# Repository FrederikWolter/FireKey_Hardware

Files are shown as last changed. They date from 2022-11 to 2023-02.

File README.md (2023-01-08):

<p align="center">
  
</p>

# FireKey - Hardware

This student research project named *FireKey* is part of the winter semester 2022 and summer semester 2023 in the
Applied Computer Science course at DHBW Mannheim. The aim is to create a macro keyboard with individually configurable
keys that allow the input of simple key combinations up to more complex sequences.

This repository is used for developing the *hardware* of *FireKey*. The corresponding firmware is developed in
the [FireKey_Firmware](https://github.com/FrederikWolter/FireKey_Firmware) repository and the configuration software
in [FireKey_Configurator](https://github.com/FrederikWolter/FireKey_Configurator).

## Structure

### *PCB*

Work in progress TODO

### *PCB_theory*

Work in progress TODO

### *3D_printing*

Work in progress TODO

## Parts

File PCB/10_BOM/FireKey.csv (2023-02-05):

Source: | C:\Users\dvd62\OneDrive\05_Semester_5_WiSe\90_Studienarbeit\FireKey_Hardware\PCB\FireKey.kicad_sch
Date: | 2/5/2023 1:17:39 PM
Tool: | Eeschema (6.0.10)
Generator: | C:\Program Files\KiCad\6.0\bin\scripting\plugins/bom_csv_grouped_by_value.py
Component Count: | 65
Individual Components:
Item | Qty | Reference(s) | Value | LibPart | Footprint | Datasheet | Part# | Supplier
 |  | C0 | 100nF | Device:C | Capacitor_SMD:C_0603_1608Metric_Pad1.08x0.95mm_HandSolder | https://www.lcsc.com/product-detail/C694249.html | C694249 | LCSC
 |  | C1 | 100nF | Device:C | Capacitor_SMD:C_0603_1608Metric_Pad1.08x0.95mm_HandSolder | https://www.lcsc.com/product-detail/C694249.html | C694249 | LCSC
 |  | C2 | 100nF | Device:C | Capacitor_SMD:C_0603_1608Metric_Pad1.08x0.95mm_HandSolder | https://www.lcsc.com/product-detail/C694249.html | C694249 | LCSC
 |  | C3 | 100nF | Device:C | Capacitor_SMD:C_0603_1608Metric_Pad1.08x0.95mm_HandSolder | https://www.lcsc.com/product-detail/C694249.html | C694249 | LCSC
 |  | C4 | 100nF | Device:C | Capacitor_SMD:C_0603_1608Metric_Pad1.08x0.95mm_HandSolder | https://www.lcsc.com/product-detail/C694249.html | C694249 | LCSC
 |  | C5 | 100nF | Device:C | Capacitor_SMD:C_0603_1608Metric_Pad1.08x0.95mm_HandSolder | https://www.lcsc.com/product-detail/C694249.html | C694249 | LCSC
 |  | C6 | 100nF | Device:C | Capacitor_SMD:C_0603_1608Metric_Pad1.08x0.95mm_HandSolder | https://www.lcsc.com/product-detail/C694249.html | C694249 | LCSC
 |  | C7 | 100nF | Device:C | Capacitor_SMD:C_0603_1608Metric_Pad1.08x0.95mm_HandSolder | https://www.lcsc.com/product-detail/C694249.html | C694249 | LCSC
 |  | C8 | 100nF | Device:C | Capacitor_SMD:C_0603_1608Metric_Pad1.08x0.95mm_HandSolder | https://www.lcsc.com/product-detail/C694249.html | C694249 | LCSC
 |  | C9 | 100nF | Device:C | Capacitor_SMD:C_0603_1608Metric_Pad1.08x0.95mm_HandSolder | https://www.lcsc.com/product-detail/C694249.html | C694249 | LCSC
 |  | C10 | 100nF | Device:C | Capacitor_SMD:C_0603_1608Metric_Pad1.08x0.95mm_HandSolder | https://www.lcsc.com/product-detail/C694249.html | C694249 | LCSC
 |  | C11 | 100nF | Device:C | Capacitor_SMD:C_0603_1608Metric_Pad1.08x0.95mm_HandSolder | https://www.lcsc.com/product-detail/C694249.html | C694249 | LCSC
 |  | C12 | 100nF | Device:C | Capacitor_SMD:C_0603_1608Metric_Pad1.08x0.95mm_HandSolder | https://www.lcsc.com/product-detail/C694249.html | C694249 | LCSC
 |  | C13 | 100nF | Device:C | Capacitor_SMD:C_0603_1608Metric_Pad1.08x0.95mm_HandSolder | https://www.lcsc.com/product-detail/C694249.html | C694249 | LCSC
 |  | C14 | 100nF | Device:C | Capacitor_SMD:C_0603_1608Metric_Pad1.08x0.95mm_HandSolder | https://www.lcsc.com/product-detail/C694249.html | C694249 | LCSC
 |  | D1 | 1N4148W | Device:D | Custom_Parts:D_SOD-123 | https://www.lcsc.com/product-detail/C2892570.html | C2892570 | LCSC
 |  | D2 | 1N4148W | Device:D | Custom_Parts:D_SOD-123 | https://www.lcsc.com/product-detail/C2892570.html | C2892570 | LCSC
 |  | D3 | 1N4148W | Device:D | Custom_Parts:D_SOD-123 | https://www.lcsc.com/product-detail/C2892570.html | C2892570 | LCSC
 |  | D4 | 1N4148W | Device:D | Custom_Parts:D_SOD-123 | https://www.lcsc.com/product-detail/C2892570.html | C2892570 | LCSC
 |  | D5 | 1N4148W | Device:D | Custom_Parts:D_SOD-123 | https://www.lcsc.com/product-detail/C2892570.html | C2892570 | LCSC
 |  | D6 | 1N4148W | Device:D | Custom_Parts:D_SOD-123 | https://www.lcsc.com/product-detail/C2892570.html | C2892570 | LCSC
 |  | D7 | 1N4148W | Device:D | Custom_Parts:D_SOD-123 | https://www.lcsc.com/product-detail/C2892570.html | C2892570 | LCSC
 |  | D8 | 1N4148W | Device:D | Custom_Parts:D_SOD-123 | https://www.lcsc.com/product-detail/C2892570.html | C2892570 | LCSC
 |  | D9 | 1N4148W | Device:D | Custom_Parts:D_SOD-123 | https://www.lcsc.com/product-detail/C2892570.html | C2892570 | LCSC
 |  | D10 | 1N4148W | Device:D | Custom_Parts:D_SOD-123 | https://www.lcsc.com/product-detail/C2892570.html | C2892570 | LCSC
 |  | D11 | 1N4148W | Device:D | Custom_Parts:D_SOD-123 | https://www.lcsc.com/product-detail/C2892570.html | C2892570 | LCSC
 |  | D12 | 1N4148W | Device:D | Custom_Parts:D_SOD-123 | https://www.lcsc.com/product-detail/C2892570.html | C2892570 | LCSC
 |  | D13 | 1N4148W | Device:D | Custom_Parts:D_SOD-123 | https://www.lcsc.com/product-detail/C2892570.html | C2892570 | LCSC
 |  | D14 | 1N4148W | Device:D | Custom_Parts:D_SOD-123 | https://www.lcsc.com/product-detail/C2892570.html | C2892570 | LCSC
 |  | D15 | 1N4148W | Device:D | Custom_Parts:D_SOD-123 | https://www.lcsc.com/product-detail/C2892570.html | C2892570 | LCSC
 |  | KEY1 | SW_MX | Custom_Parts:SW_MX_1u | Custom_Parts:SW_Cherry_MX_1.00u_PCB_CleanFront | https://de.aliexpress.com/item/1005003981373212.html | - | AliExpress
 |  | KEY2 | SW_MX | Custom_Parts:SW_MX_1u | Custom_Parts:SW_Cherry_MX_1.00u_PCB_CleanFront | https://de.aliexpress.com/item/1005003981373212.html | - | AliExpress
 |  | KEY3 | SW_MX | Custom_Parts:SW_MX_1u | Custom_Parts:SW_Cherry_MX_1.00u_PCB_CleanFront | https://de.aliexpress.com/item/1005003981373212.html | - | AliExpress
 |  | KEY4 | SW_MX | Custom_Parts:SW_MX_1u | Custom_Parts:SW_Cherry_MX_1.00u_PCB_CleanFront | https://de.aliexpress.com/item/1005003981373212.html | - | AliExpress
 |  | KEY5 | SW_MX | Custom_Parts:SW_MX_1u | Custom_Parts:SW_Cherry_MX_1.00u_PCB_CleanFront | https://de.aliexpress.com/item/1005003981373212.html | - | AliExpress
 |  | KEY6 | SW_MX | Custom_Parts:SW_MX_1u | Custom_Parts:SW_Cherry_MX_1.00u_PCB_CleanFront | https://de.aliexpress.com/item/1005003981373212.html | - | AliExpress
 |  | KEY7 | SW_MX | Custom_Parts:SW_MX_1u | Custom_Parts:SW_Cherry_MX_1.00u_PCB_CleanFront | https://de.aliexpress.com/item/1005003981373212.html | - | AliExpress
 |  | KEY8 | SW_MX | Custom_Parts:SW_MX_1u | Custom_Parts:SW_Cherry_MX_1.00u_PCB_CleanFront | https://de.aliexpress.com/item/1005003981373212.html | - | AliExpress
 |  | KEY9 | SW_MX | Custom_Parts:SW_MX_1u | Custom_Parts:SW_Cherry_MX_1.00u_PCB_CleanFront | https://de.aliexpress.com/item/1005003981373212.html | - | AliExpress
 |  | KEY10 | SW_MX | Custom_Parts:SW_MX_1u | Custom_Parts:SW_Cherry_MX_1.00u_PCB_CleanFront | https://de.aliexpress.com/item/1005003981373212.html | - | AliExpress
 |  | KEY11 | SW_MX | Custom_Parts:SW_MX_1u | Custom_Parts:SW_Cherry_MX_1.00u_PCB_CleanFront | https://de.aliexpress.com/item/1005003981373212.html | - | AliExpress
 |  | KEY12 | SW_MX | Custom_Parts:SW_MX_1u | Custom_Parts:SW_Cherry_MX_1.00u_PCB_CleanFront | https://de.aliexpress.com/item/1005003981373212.html | - | AliExpress
 |  | KEY13 | SW_MX | Custom_Parts:SW_MX_1u | Custom_Parts:SW_Cherry_MX_1.00u_PCB_CleanFront | https://de.aliexpress.com/item/1005003981373212.html | - | AliExpress
 |  | KEY14 | SW_MX | Custom_Parts:SW_MX_1u | Custom_Parts:SW_Cherry_MX_1.00u_PCB_CleanFront | https://de.aliexpress.com/item/1005003981373212.html | - | AliExpress
 |  | KEY15 | SW_MX | Custom_Parts:SW_MX_1u | Custom_Parts:SW_Cherry_MX_1.00u_PCB_CleanFront | https://de.aliexpress.com/item/1005003981373212.html | - | AliExpress
 |  | LED0 | SK6812 | Custom_Parts:DY-S352818{slash}6812-2T | Custom_Parts:DY-S352818-6812-2T | https://www.lcsc.com/product-detail/C524051.html | C524051 | LCSC
 |  | LED1 | SK6812 | Custom_Parts:DY-S352818{slash}6812-2T | Custom_Parts:DY-S352818-6812-2T | https://www.lcsc.com/product-detail/C524051.html | C524051 | LCSC
 |  | LED2 | SK6812 | Custom_Parts:DY-S352818{slash}6812-2T | Custom_Parts:DY-S352818-6812-2T | https://www.lcsc.com/product-detail/C524051.html | C524051 | LCSC
 |  | LED3 | SK6812 | Custom_Parts:DY-S352818{slash}6812-2T | Custom_Parts:DY-S352818-6812-2T | https://www.lcsc.com/product-detail/C524051.html | C524051 | LCSC
 |  | LED4 | SK6812 | Custom_Parts:DY-S352818{slash}6812-2T | Custom_Parts:DY-S352818-6812-2T | https://www.lcsc.com/product-detail/C524051.html | C524051 | LCSC
 |  | LED5 | SK6812 | Custom_Parts:DY-S352818{slash}6812-2T | Custom_Parts:DY-S352818-6812-2T | https://www.lcsc.com/product-detail/C524051.html | C524051 | LCSC
 |  | LED6 | SK6812 | Custom_Parts:DY-S352818{slash}6812-2T | Custom_Parts:DY-S352818-6812-2T | https://www.lcsc.com/product-detail/C524051.html | C524051 | LCSC
 |  | LED7 | SK6812 | Custom_Parts:DY-S352818{slash}6812-2T | Custom_Parts:DY-S352818-6812-2T | https://www.lcsc.com/product-detail/C524051.html | C524051 | LCSC
 |  | LED8 | SK6812 | Custom_Parts:DY-S352818{slash}6812-2T | Custom_Parts:DY-S352818-6812-2T | https://www.lcsc.com/product-detail/C524051.html | C524051 | LCSC
 |  | LED9 | SK6812 | Custom_Parts:DY-S352818{slash}6812-2T | Custom_Parts:DY-S352818-6812-2T | https://www.lcsc.com/product-detail/C524051.html | C524051 | LCSC
 |  | LED10 | SK6812 | Custom_Parts:DY-S352818{slash}6812-2T | Custom_Parts:DY-S352818-6812-2T | https://www.lcsc.com/product-detail/C524051.html | C524051 | LCSC
 |  | LED11 | SK6812 | Custom_Parts:DY-S352818{slash}6812-2T | Custom_Parts:DY-S352818-6812-2T | https://www.lcsc.com/product-detail/C524051.html | C524051 | LCSC
 |  | LED12 | SK6812 | Custom_Parts:DY-S352818{slash}6812-2T | Custom_Parts:DY-S352818-6812-2T | https://www.lcsc.com/product-detail/C524051.html | C524051 | LCSC
 |  | LED13 | SK6812 | Custom_Parts:DY-S352818{slash}6812-2T | Custom_Parts:DY-S352818-6812-2T | https://www.lcsc.com/product-detail/C524051.html | C524051 | LCSC
 |  | LED14 | SK6812 | Custom_Parts:DY-S352818{slash}6812-2T | Custom_Parts:DY-S352818-6812-2T | https://www.lcsc.com/product-detail/C524051.html | C524051 | LCSC
 |  | OLED1 | OLED_1.3_4P_GV | Custom_Modules:OLED_1.3_4P_GV | Custom_Module:OLED_1.3_4P_M2.5Holes_CleanFront | https://de.aliexpress.com/item/1005004131362533.html | - | AliExpress
 |  | OLED2 | OLED_1.3_4P_GV | Custom_Modules:OLED_1.3_4P_GV | Custom_Module:OLED_1.3_4P_M2.5Holes_CleanFront | https://de.aliexpress.com/item/1005004131362533.html | - | AliExpress
 |  | R1 | 470 | Device:R | Resistor_SMD:R_0603_1608Metric_Pad0.98x0.95mm_HandSolder | https://www.lcsc.com/product-detail/C23179.html | C23179 | LCSC
 |  | SW1 | SW_MEC_4A | Custom_Parts:SW_MEC_4P | Button_Switch_SMD:SW_SPST_TL3342 | https://www.lcsc.com/product-detail/C2888878.html | C2888878 | LCSC
 |  | U1 | Arduino_Pro_Micro_USB-C | Custom_MCU:Arduino_Pro_Micro_USB-C | Custom_MCU:Arduino_Pro_Micro_USB-C_CleanFront | https://de.aliexpress.com/item/1005004771851259.html | - | AliExpress
Collated Components:
Item | Qty | Reference(s) | Value | LibPart | Footprint | Datasheet | Part# | Supplier
1 | 15 | C0, C1, C2, C3, C4, C5, C6, C7, C8, C9, C10, C11, C12, C13, C14 | 100nF | Device:C | Capacitor_SMD:C_0603_1608Metric_Pad1.08x0.95mm_HandSolder | https://www.lcsc.com/product-detail/C694249.html | C694249 | LCSC
2 | 15 | D1, D2, D3, D4, D5, D6, D7, D8, D9, D10, D11, D12, D13, D14, D15 | 1N4148W | Device:D | Custom_Parts:D_SOD-123 | https://www.lcsc.com/product-detail/C2892570.html | C2892570 | LCSC
3 | 15 | KEY1, KEY2, KEY3, KEY4, KEY5, KEY6, KEY7, KEY8, KEY9, KEY10, KEY11, KEY12, KEY13, KEY14, KEY15 | SW_MX | Custom_Parts:SW_MX_1u | Custom_Parts:SW_Cherry_MX_1.00u_PCB_CleanFront | https://de.aliexpress.com/item/1005003981373212.html | - | AliExpress
4 | 15 | LED0, LED1, LED2, LED3, LED4, LED5, LED6, LED7, LED8, LED9, LED10, LED11, LED12, LED13, LED14 | SK6812 | Custom_Parts:DY-S352818{slash}6812-2T | Custom_Parts:DY-S352818-6812-2T | https://www.lcsc.com/product-detail/C524051.html | C524051 | LCSC
5 | 2 | OLED1, OLED2 | OLED_1.3_4P_GV | Custom_Modules:OLED_1.3_4P_GV | Custom_Module:OLED_1.3_4P_M2.5Holes_CleanFront | https://de.aliexpress.com/item/1005004131362533.html | - | AliExpress
6 | 1 | R1 | 470 | Device:R | Resistor_SMD:R_0603_1608Metric_Pad0.98x0.95mm_HandSolder | https://www.lcsc.com/product-detail/C23179.html | C23179 | LCSC
7 | 1 | SW1 | SW_MEC_4A | Custom_Parts:SW_MEC_4P | Button_Switch_SMD:SW_SPST_TL3342 | https://www.lcsc.com/product-detail/C2888878.html | C2888878 | LCSC
8 | 1 | U1 | Arduino_Pro_Micro_USB-C | Custom_MCU:Arduino_Pro_Micro_USB-C | Custom_MCU:Arduino_Pro_Micro_USB-C_CleanFront | https://de.aliexpress.com/item/1005004771851259.html | - | AliExpress

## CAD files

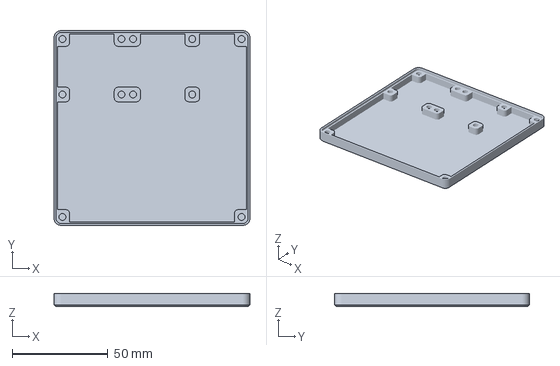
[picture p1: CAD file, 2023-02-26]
3D_printing/Housing_Bottom.3mf
102.1 x 101.5 x 7.00 mm

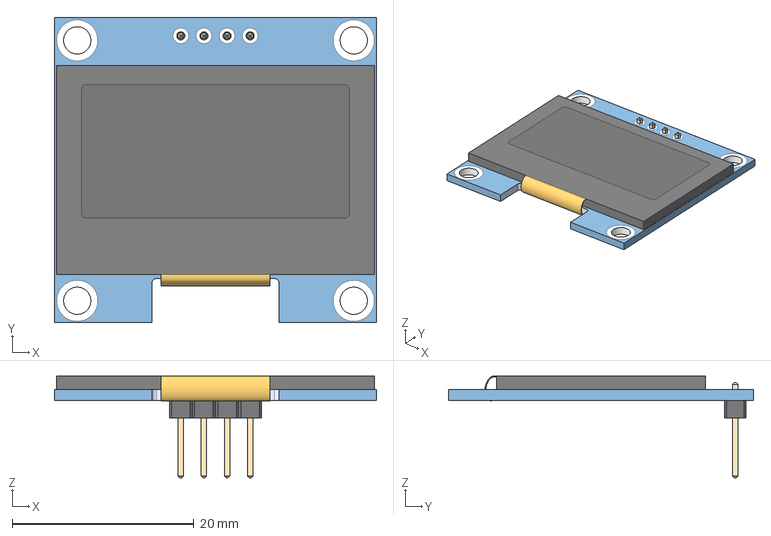
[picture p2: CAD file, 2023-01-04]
PCB/20_Custom_Libraries/3D_Models/OLED_1.3_IIC.STEP
35.4 x 33.5 x 11.2 mm

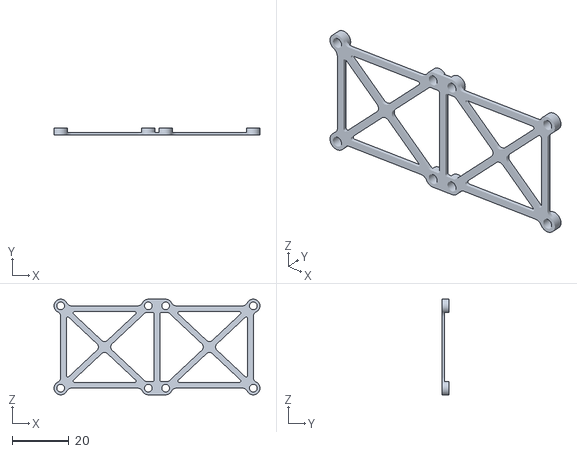
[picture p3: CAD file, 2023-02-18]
3D_printing/Display_Standof_2.5.stl
72.3 x 2.54 x 33.6

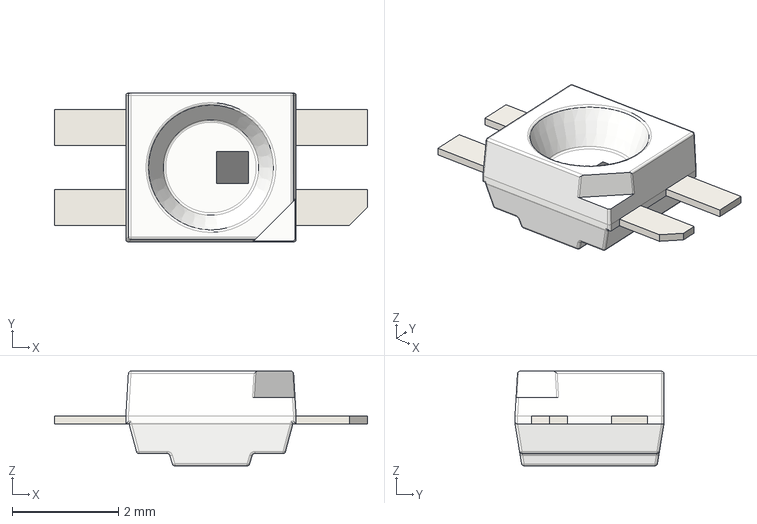
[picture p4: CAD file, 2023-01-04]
PCB/20_Custom_Libraries/3D_Models/LED_SK6812MINI-E.STEP
5.88 x 2.80 x 1.78 mm

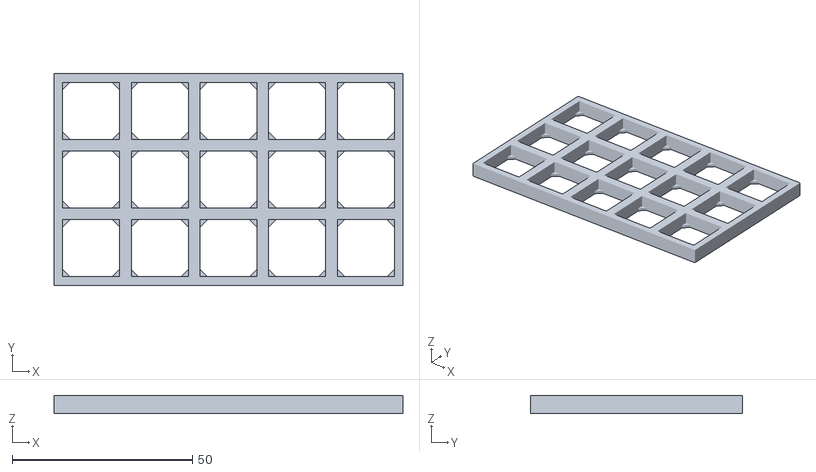
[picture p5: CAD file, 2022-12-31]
3D_printing/Cherry_Switch_Alignment_Jig_5x3.stl
96.8 x 58.7 x 5.00

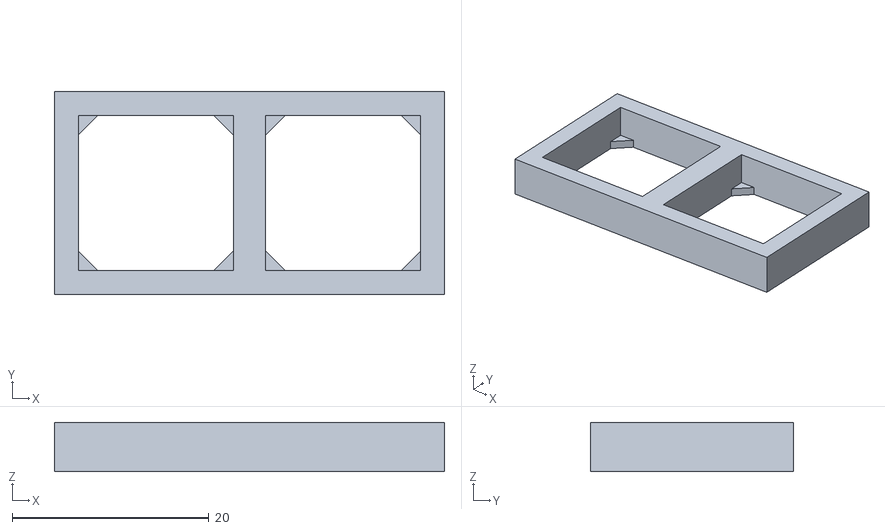
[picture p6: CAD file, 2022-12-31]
3D_printing/Cherry_Switch_Alignment_Jig_1x2.stl
39.7 x 20.6 x 5.00

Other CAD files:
3D_printing/Cherry_Switch_Alignment_Jig.ipt
3D_printing/Display_Standof_2.5.ipt
3D_printing/Housing_Bottom.idw
3D_printing/Housing_Bottom.ipt
3D_printing/Housing_Bottom.stl

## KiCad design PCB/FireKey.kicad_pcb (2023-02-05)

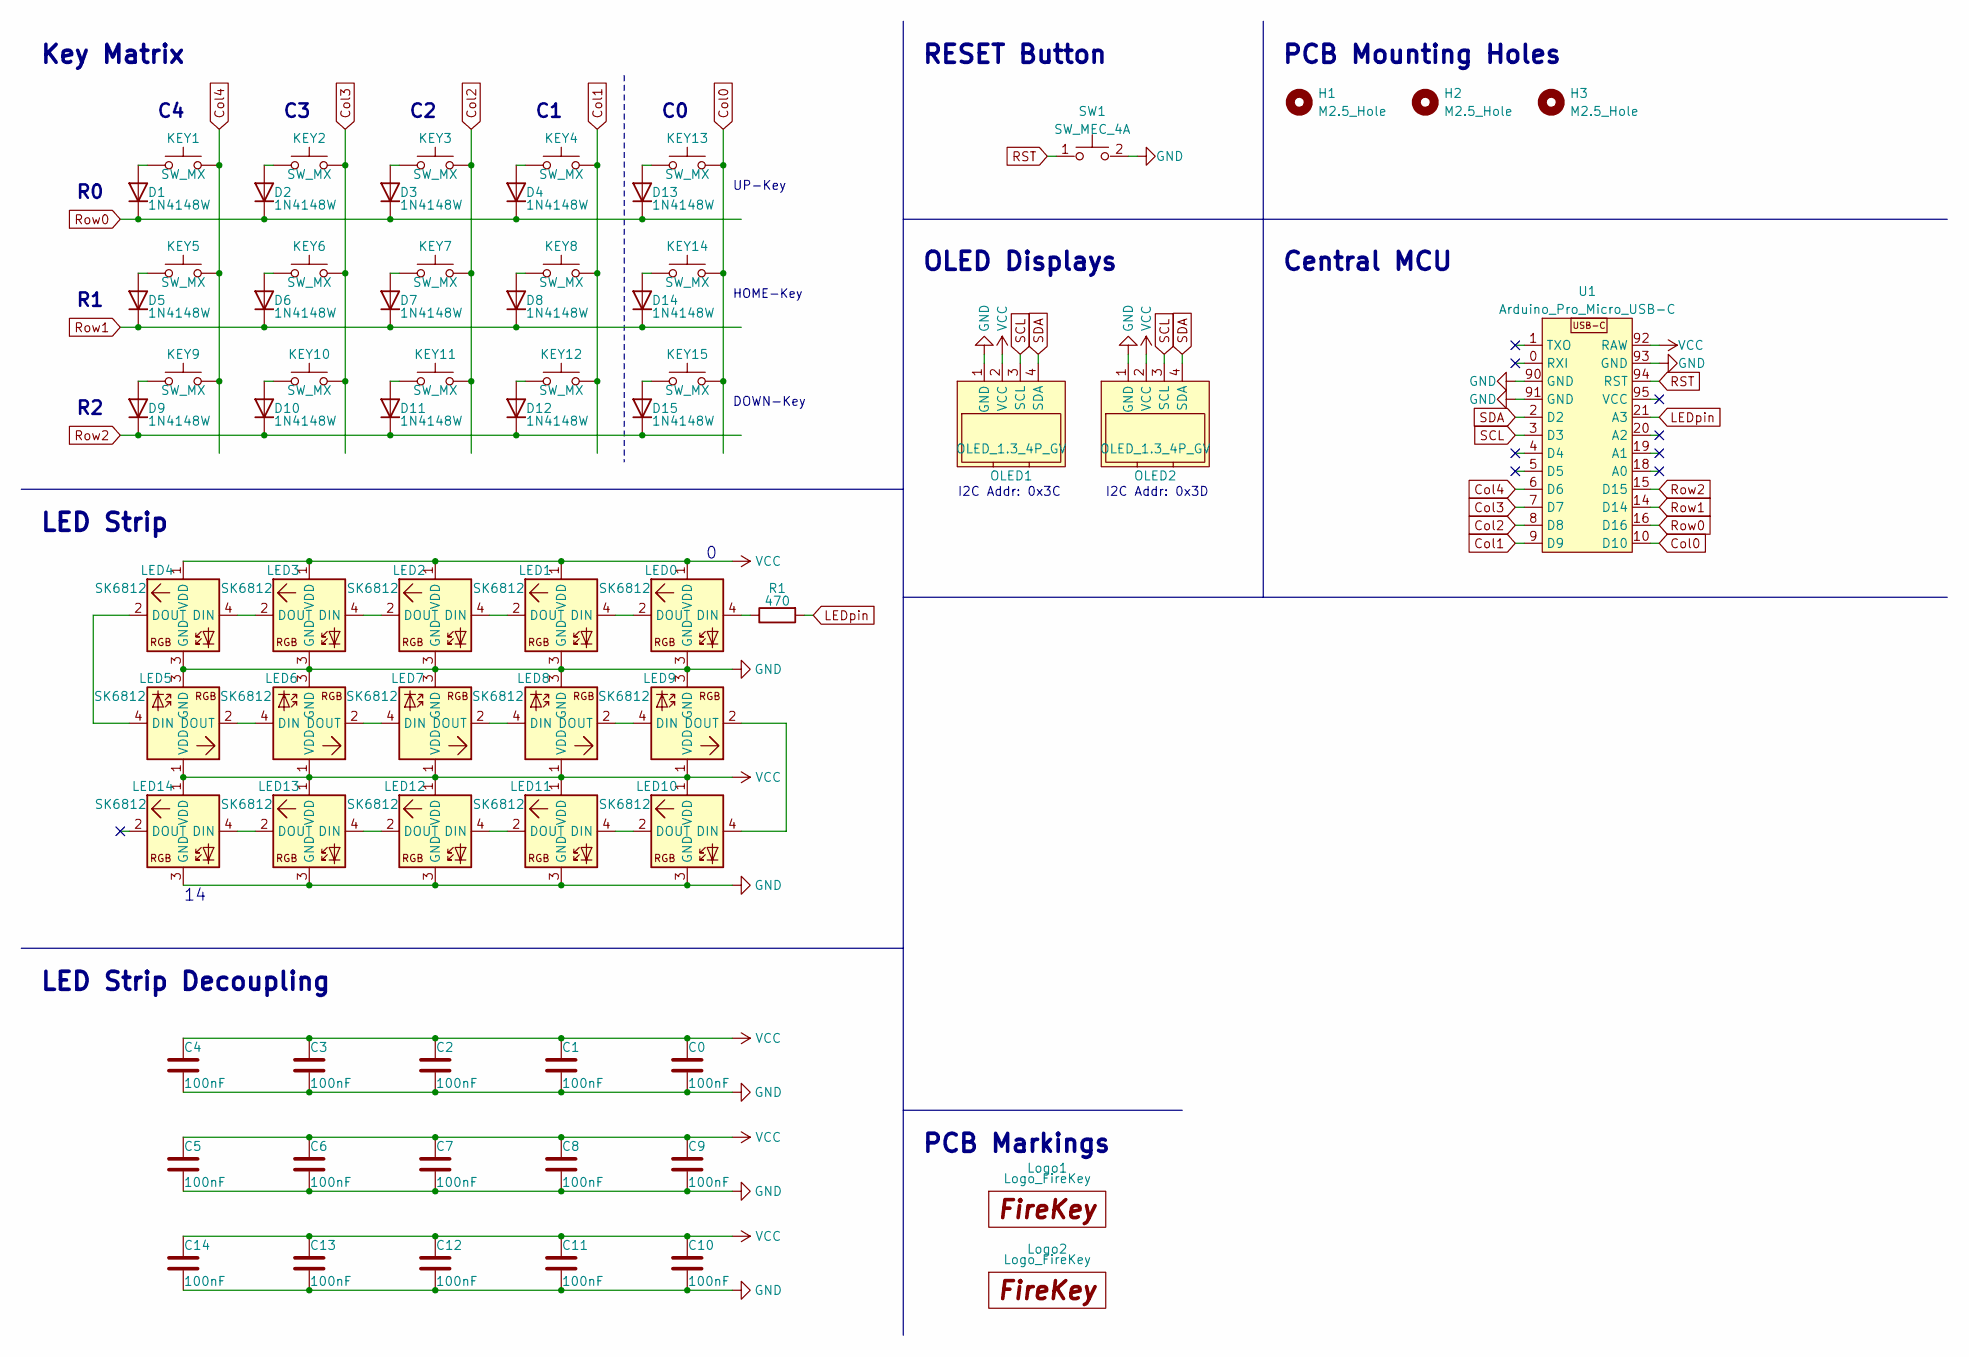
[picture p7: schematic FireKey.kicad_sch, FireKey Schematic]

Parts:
C0, C1, C2, C3, C4, C5, C6, C7, C8, C9, C10, C11, C12, C13, C14: 100nF; C_0603_1608Metric_Pad1.08x0.95mm_HandSolder; Part# C694249
D1, D2, D3, D4, D5, D6, D7, D8, D9, D10, D11, D12, D13, D14, D15: 1N4148W; D_SOD-123; Part# C2892570
H1, H2, H3: M2.5_Hole; MountingHole_2.7mm_M2.5
KEY1, KEY2, KEY3, KEY4, KEY5, KEY6, KEY7, KEY8, KEY9, KEY10, KEY11, KEY12, KEY13, KEY14, KEY15: SW_MX; SW_Cherry_MX_1.00u_PCB_CleanFront
LED0, LED1, LED2, LED3, LED4, LED5, LED6, LED7, LED8, LED9, LED10, LED11, LED12, LED13, LED14: SK6812; DY-S352818-6812-2T; Part# C524051
Logo1: Logo_FireKey; Logo_FireKey_22x6.4
Logo2: Logo_FireKey; Logo_FireKey_12x3.5
OLED1, OLED2: OLED_1.3_4P_GV; OLED_1.3_4P_M2.5Holes_CleanFront
R1: 470; R_0603_1608Metric_Pad0.98x0.95mm_HandSolder; Part# C23179
SW1: SW_MEC_4A; SW_SPST_TL3342; Part# C2888878
U1: Arduino_Pro_Micro_USB-C; Arduino_Pro_Micro_USB-C_CleanFront

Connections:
Col0: KEY13.2 (B), KEY14.2 (B), KEY15.2 (B), U1.10 (D10)
Col1: KEY4.2 (B), KEY8.2 (B), KEY12.2 (B), U1.9 (D9)
Col2: KEY3.2 (B), KEY7.2 (B), KEY11.2 (B), U1.8 (D8)
Col3: KEY2.2 (B), KEY6.2 (B), KEY10.2 (B), U1.7 (D7)
Col4: KEY1.2 (B), KEY5.2 (B), KEY9.2 (B), U1.6 (D6)
GND: C0.2, C1.2, C2.2, C3.2, C4.2, C5.2, C6.2, C7.2, C8.2, C9.2, C10.2, C11.2, C12.2, C13.2, C14.2, LED0.3 (GND), LED1.3 (GND), LED2.3 (GND), LED3.3 (GND), LED4.3 (GND), LED5.3 (GND), LED6.3 (GND), LED7.3 (GND), LED8.3 (GND), LED9.3 (GND), LED10.3 (GND), LED11.3 (GND), LED12.3 (GND), LED13.3 (GND), LED14.3 (GND), OLED1.1 (GND), OLED2.1 (GND), SW1.2, U1.90 (GND), U1.91 (GND), U1.93 (GND)
LEDpin: R1.2, U1.21 (A3)
unnamed: D1.2 (A), KEY1.1 (A)
unnamed: D2.2 (A), KEY2.1 (A)
unnamed: D3.2 (A), KEY3.1 (A)
unnamed: D4.2 (A), KEY4.1 (A)
unnamed: D5.2 (A), KEY5.1 (A)
unnamed: D6.2 (A), KEY6.1 (A)
unnamed: D7.2 (A), KEY7.1 (A)
unnamed: D8.2 (A), KEY8.1 (A)
unnamed: D9.2 (A), KEY9.1 (A)
unnamed: D10.2 (A), KEY10.1 (A)
unnamed: D11.2 (A), KEY11.1 (A)
unnamed: D12.2 (A), KEY12.1 (A)
unnamed: D13.2 (A), KEY13.1 (A)
unnamed: D14.2 (A), KEY14.1 (A)
unnamed: D15.2 (A), KEY15.1 (A)
unnamed: LED0.2 (DOUT), LED1.4 (DIN)
unnamed: LED0.4 (DIN), R1.1
unnamed: LED1.2 (DOUT), LED2.4 (DIN)
unnamed: LED2.2 (DOUT), LED3.4 (DIN)
unnamed: LED3.2 (DOUT), LED4.4 (DIN)
unnamed: LED4.2 (DOUT), LED5.4 (DIN)
unnamed: LED5.2 (DOUT), LED6.4 (DIN)
unnamed: LED6.2 (DOUT), LED7.4 (DIN)
unnamed: LED7.2 (DOUT), LED8.4 (DIN)
unnamed: LED8.2 (DOUT), LED9.4 (DIN)
unnamed: LED10.2 (DOUT), LED11.4 (DIN)
unnamed: LED9.2 (DOUT), LED10.4 (DIN)
unnamed: LED11.2 (DOUT), LED12.4 (DIN)
unnamed: LED12.2 (DOUT), LED13.4 (DIN)
unnamed: LED13.2 (DOUT), LED14.4 (DIN)
RST: SW1.1, U1.94 (RST)
Row0: D1.1 (K), D2.1 (K), D3.1 (K), D4.1 (K), D13.1 (K), U1.16 (D16)
Row1: D5.1 (K), D6.1 (K), D7.1 (K), D8.1 (K), D14.1 (K), U1.14 (D14)
Row2: D9.1 (K), D10.1 (K), D11.1 (K), D12.1 (K), D15.1 (K), U1.15 (D15)
SCL: OLED1.3 (SCL), OLED2.3 (SCL), U1.3 (D3)
SDA: OLED1.4 (SDA), OLED2.4 (SDA), U1.2 (D2)
VCC: C0.1, C1.1, C2.1, C3.1, C4.1, C5.1, C6.1, C7.1, C8.1, C9.1, C10.1, C11.1, C12.1, C13.1, C14.1, LED0.1 (VDD), LED1.1 (VDD), LED2.1 (VDD), LED3.1 (VDD), LED4.1 (VDD), LED5.1 (VDD), LED6.1 (VDD), LED7.1 (VDD), LED8.1 (VDD), LED9.1 (VDD), LED10.1 (VDD), LED11.1 (VDD), LED12.1 (VDD), LED13.1 (VDD), LED14.1 (VDD), OLED1.2 (VCC), OLED2.2 (VCC), U1.92 (RAW)

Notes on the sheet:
RESET Button
DOWN-Key
UP-Key
LED Strip
HOME-Key
I2C Addr: 0x3C
PCB Mounting Holes
Key Matrix
I2C Addr: 0x3D
OLED Displays
Central MCU
LED Strip Decoupling
PCB Markings

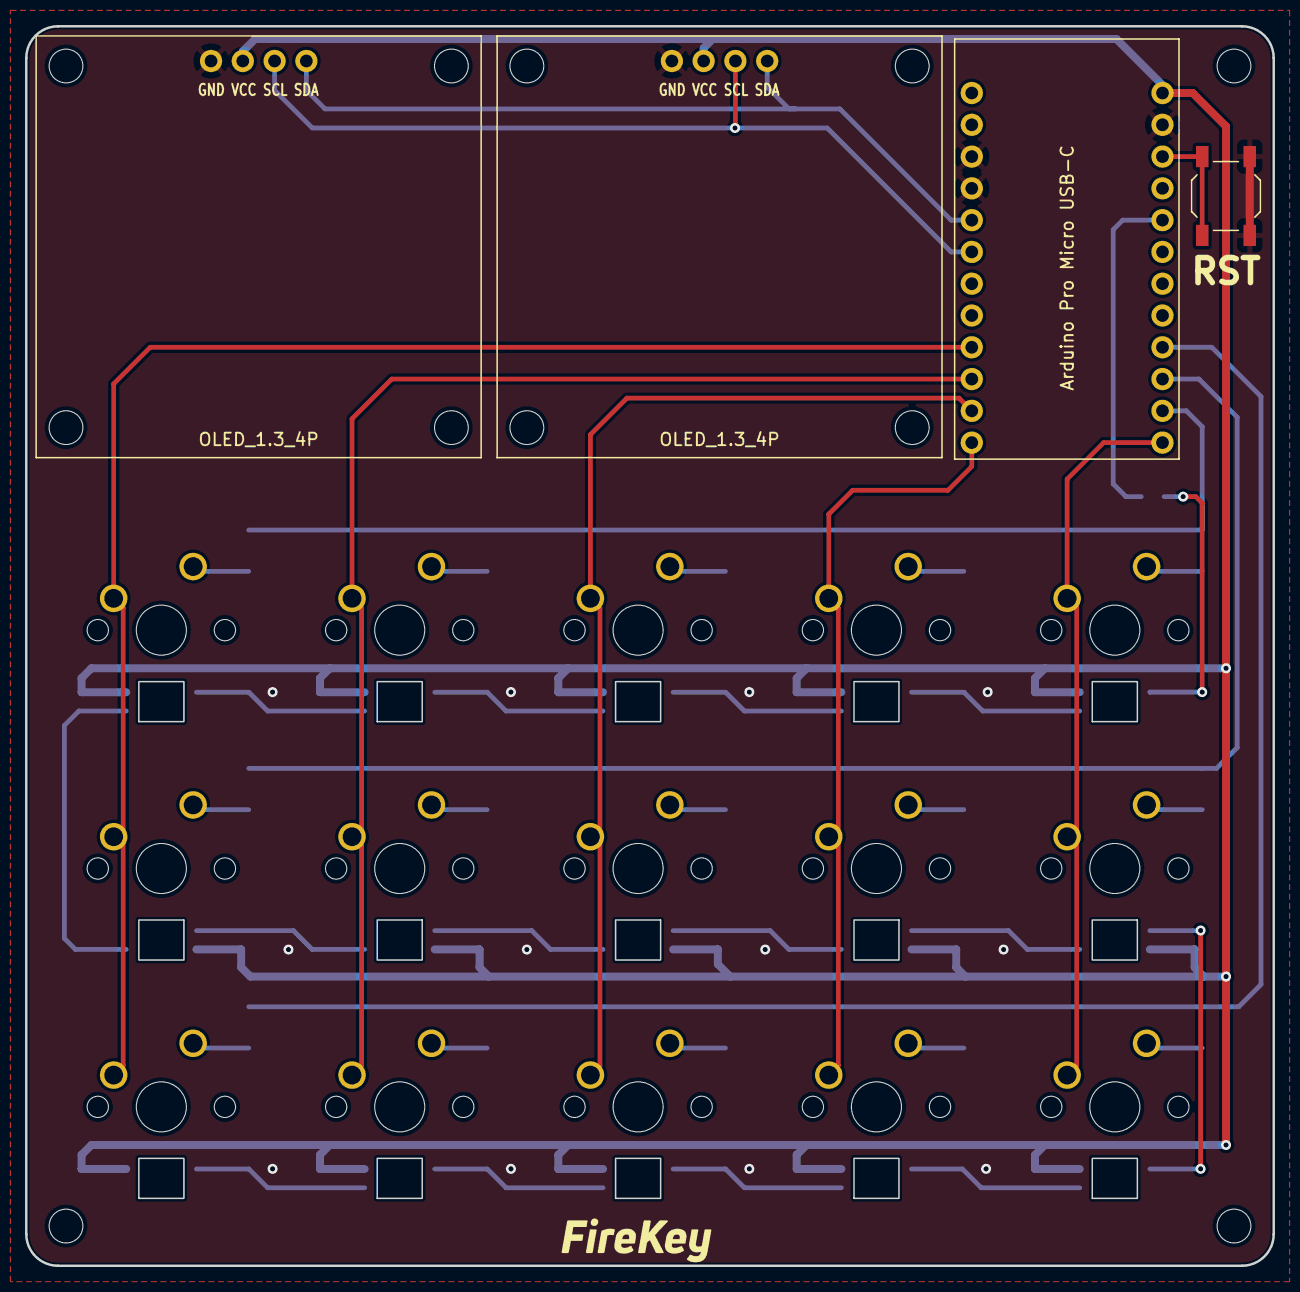
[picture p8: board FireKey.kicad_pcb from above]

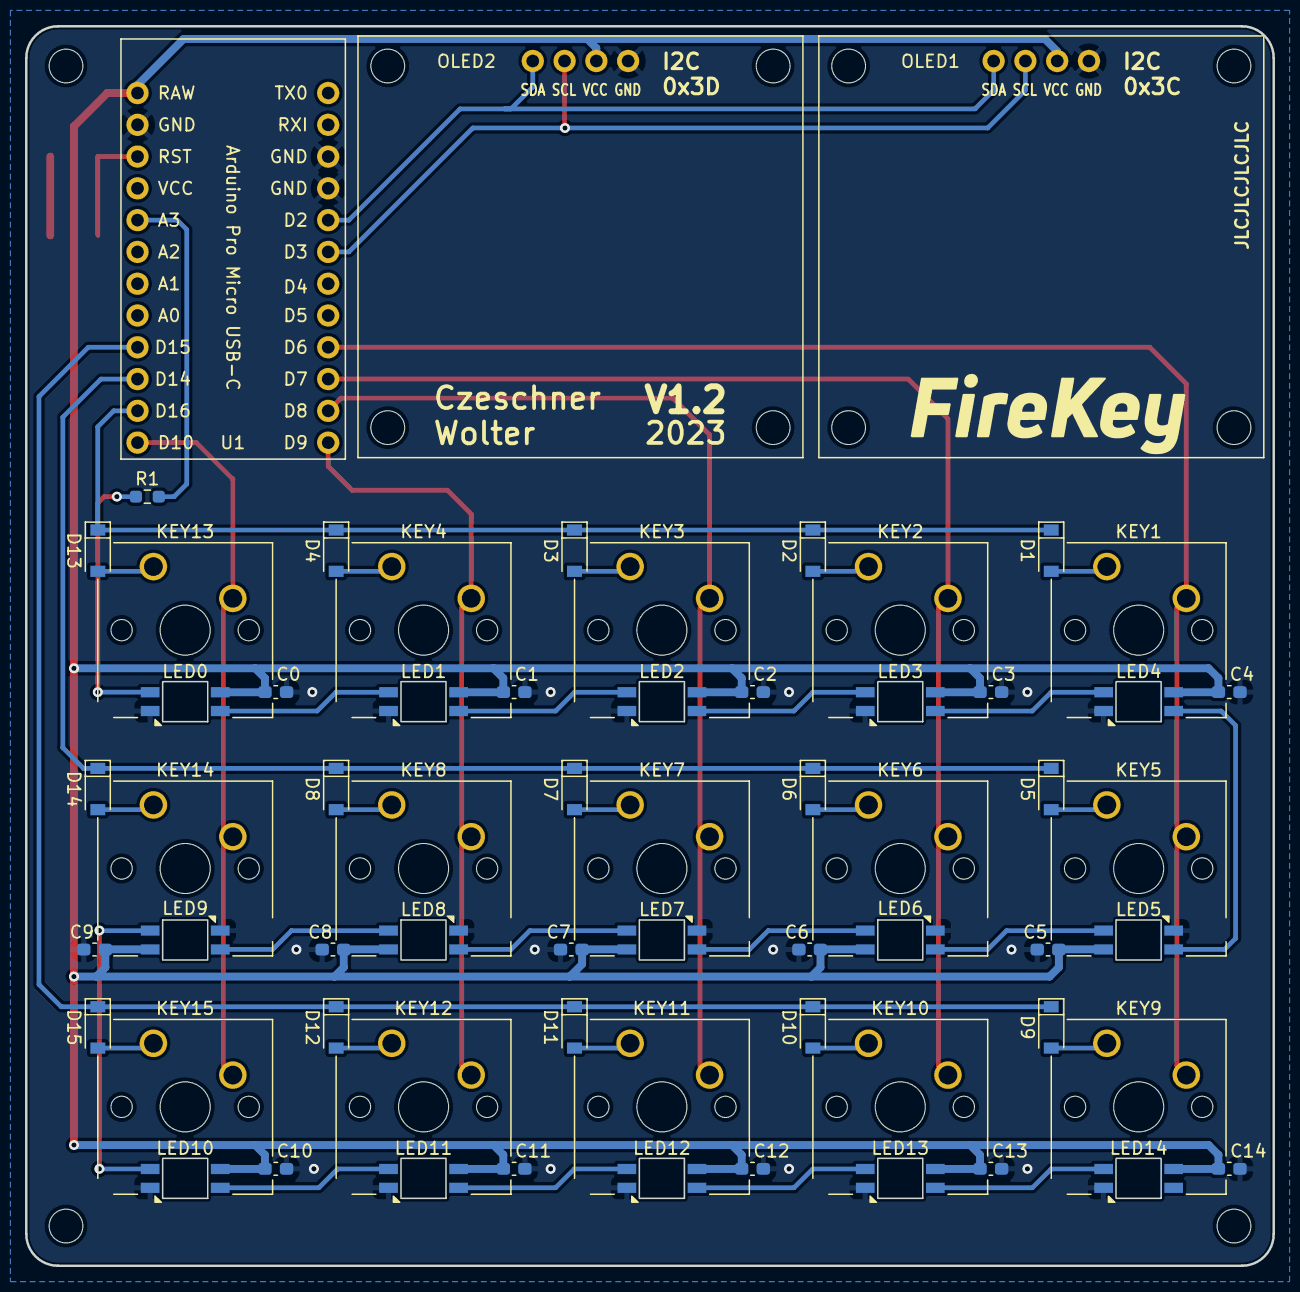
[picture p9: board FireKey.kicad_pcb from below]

Board: 2 copper layers, 99.7 x 99.1 mm, 70 parts (47 on the bottom side), 44 nets.

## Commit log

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2022-11-13 add empty KiCad project
    [FireKey.kicad_pcb, FireKey.kicad_sch]
2022-11-13 Started recreating V0 schematic in KiCad
    [FireKey.kicad_sch]
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2022-11-14 worked on schematic; added net labels
    [FireKey.kicad_sch]
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2022-11-14 finished recreating V0 schematic in KiCad
    [FireKey.kicad_sch]
2022-11-14 generated current version of BOM
    [FireKey.csv]
2022-11-14 updated and worked on BOM
    [FireKey.csv]
2022-11-14 BOM management; started footprint assignment
    [FireKey.kicad_sch]
2022-11-15 shortend link refrences to datasheets
    [FireKey.kicad_sch]
2022-11-15 Added second theory KiCad project
    [FireKey_Theory.kicad_pcb, FireKey_Theory.kicad_sch]
2022-11-15 fixed FireKe_Theory KiCad project location
    [FireKey_Theory.kicad_pcb, FireKey_Theory.kicad_sch]
2022-11-15 Set up theory project
    [FireKey_Theory.kicad_sch]
2022-11-15 playing around with schematic segmentation
    [FireKey.kicad_sch]
2022-11-17 worked on schematic structure
    [FireKey.kicad_sch]
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2022-11-17 start adding custom footprints
    [FireKey.kicad_sch]
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2022-11-19 created pcb design file
    [FireKey.kicad_pcb]
2022-11-19 worked on pcb settings and capabilities
    [FireKey.kicad_pcb]
2022-11-20 simplified led strip tracing
    [FireKey.kicad_sch]
2022-11-20 make key matrix schematic represent actual layout
    [FireKey.kicad_sch]
2022-11-20 mirrored leds to match pcb; changed key numbering to match led index
    [FireKey.kicad_sch]
2022-11-20 worked on pcb design
    [FireKey.kicad_pcb]
2022-11-27 small changes to schematic
    [FireKey.kicad_sch]
2022-11-27 moved main components on pcb
    [FireKey.kicad_pcb]
2022-11-27 fixed diode naming in schematic
    [FireKey.kicad_sch]
2022-11-27 worked on placing parts on pcb
    [FireKey.kicad_pcb]
2022-11-27 placed all parts on pcb
    [FireKey.kicad_pcb]
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2022-11-27 fixed mx switches
    [FireKey.kicad_pcb, FireKey.kicad_sch]
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2022-11-27 fixed rst switch
    [FireKey.kicad_pcb, FireKey.kicad_sch]
2022-11-29 worked on tracing pcb
    [FireKey.kicad_pcb]
2022-11-29 worked on DRC errors
    [FireKey.kicad_pcb, FireKey.kicad_sch]
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2022-11-30 fixed version number to V0.1
    [FireKey.kicad_pcb, FireKey.kicad_sch]
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2022-12-04 added Logo as footprint; worked on DRC
    [FireKey.kicad_pcb]
2022-12-04 setup gerber export; updated rev
    [FireKey.kicad_pcb, FireKey.kicad_sch]
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2022-12-08 small changes to schematic; passed DRC
    [FireKey.kicad_sch]
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2022-12-08 small changes to pcb; passed DRC
    [FireKey.kicad_pcb]
2022-12-08 generated Gerber for V0.1.2
    [FireKey-B_Cu.gbr, FireKey-B_Mask.gbr, FireKey-B_Paste.gbr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]
2022-12-08 started working on V1.0.0
    [FireKey.kicad_sch]
2022-12-10 Worked on V1.0.0 Schematic
    [FireKey.kicad_sch]
2022-12-12 fixed RST SW footprint
2022-12-12 Worked on V1.0.0 PCB
    [FireKey.kicad_pcb]
2022-12-12 deleted unused Mounting Holes in schematic
    [FireKey.kicad_sch]
2022-12-12 group key sets on pcb
    [FireKey.kicad_pcb]
2022-12-16 updated key labels in schematic
    [FireKey.kicad_sch]
2022-12-16 worked on key matrix routing
    [FireKey.kicad_pcb]
2022-12-18 minor change to schematic
    [FireKey.kicad_sch]
2022-12-18 worked on pcb routing
    [FireKey.kicad_pcb]
2022-12-18 changed col order; switched to new sw footprint
    [FireKey.kicad_sch]
2022-12-18 worked on PCB tracing and DRC errors
    [FireKey.kicad_pcb]
2022-12-23 removed unused mounting holes on schematic
    [FireKey.kicad_sch]
2022-12-23 worked on DRC errors; routing
    [FireKey.kicad_pcb]
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2022-12-23 added second logo to schematic
    [FireKey.kicad_sch]
2022-12-23 small changes to PCB; placing logos
    [FireKey.kicad_pcb]
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2022-12-25 DRC pass PCB V1.0.0
    [FireKey.kicad_pcb]
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2022-12-31 tuned clearance; added 5x3 version
    [Cherry_Switch_Alignment_Jig.ipt, Cherry_Switch_Alignment_Jig_5x3.stl, Cherry_Switch_Alignment_Jig_test_1x2.stl]
2023-01-03 renamed dir to 3D_printing
    [Cherry_Switch_Alignment_Jig.ipt, Cherry_Switch_Alignment_Jig_5x3.stl, Cherry_Switch_Alignment_Jig_test_1x2.stl]
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2023-01-04 LED added 3D Modell
    [LED_SK6812MINI-E.STEP]
2023-01-04 OLED added 3D Modell
    [OLED_1.3_IIC.STEP]
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2023-01-04 updated PCB to use 3D Modells
    [FireKey.kicad_pcb]
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2023-01-07 added more dimensions to pcb
    [FireKey.kicad_pcb]
2023-01-07 generated Gerbers for V1.0.1
    [FireKey-B_Cu.gbr, FireKey-B_Mask.gbr, FireKey-B_Paste.gbr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]
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2023-01-08 smaller thermal spoke for gnd plane
    [FireKey.kicad_pcb]
2023-01-08 changed schematic to use two I2C buses
    [FireKey.kicad_sch]
2023-01-08 updated symbols in schematic
    [FireKey.kicad_sch]
2023-01-08 switched I2C_1 and I2C_2 for better routing
    [FireKey.kicad_sch]
2023-01-08 routed new I2C bus on pcb
    [FireKey.kicad_pcb]
2023-01-16 automatic changes to pcb
    [FireKey.kicad_pcb]
2023-01-16 generated gerbers for V1.1.0
    [FireKey-B_Cu.gbr, FireKey-B_Mask.gbr, FireKey-B_Paste.gbr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]
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2023-01-16 Starting HV1.2.0 by changing to new displays
    [FireKey.kicad_sch]
2023-01-16 changing pcb to new displays
    [FireKey.kicad_pcb]
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2023-01-16 minor changes to labels
    [FireKey.kicad_pcb, FireKey.kicad_sch]
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2023-02-05 changed to HV1.2.1; switched to cleanFront footprints
    [FireKey.kicad_sch]
2023-02-05 created HV1.2.1 PCB; minor changes to silkscreen
    [FireKey.kicad_pcb]
2023-02-05 updated example part suppliers
    [FireKey.kicad_sch]
2023-02-05 generated BOM for HV1.2.1
    [FireKey.csv]
2023-02-05 updated pcb with supplier changes
    [FireKey.kicad_pcb]
2023-02-05 generated gerber for HV1.2.1
    [FireKey-B_Cu.gbr, FireKey-B_Mask.gbr, FireKey-B_Paste.gbr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]
2023-02-18 Started working on a potential display standoff
    [Display_Standof_2.5.ipt, Display_Standof_2.5.stl]
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2023-02-18 worked on 3d print models
    [Cherry_Switch_Alignment_Jig.ipt, Display_Standof_2.5.ipt]
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2023-04-15 Changes sub sheets orientation in theory
    [FireKey_Theory.kicad_sch]
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2023-04-21 fixed annotation in 2_oled
    [2_OLED_Complete.kicad_sch]
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
